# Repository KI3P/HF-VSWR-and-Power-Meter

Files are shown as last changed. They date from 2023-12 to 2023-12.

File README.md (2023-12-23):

# HF-VSWR-and-Power-Meter

System that measures the VSWR and power level of transmitter signals in the HF bands (3.5 MHz to 30 MHz) with better than 5% accuracy for VSWRs below 3.0. For a detailed explanation of its operation, see [its project page](https://ko4thb.github.io/2023/12/23/vswr_and_power_meter.html).

Gerbers were generated for manufacture by JLCPCB.

Credit: thanks to [G3TXQ](http://karinya.net/g3txq/swr_meter/) for sharing his SWR meter design and [schematic diagram](http://karinya.net/g3txq/swr_meter/schematic.jpg). Thanks to N7DDC for sharing the design of the [ATU-100 antenna tuner](https://github.com/Dfinitski/N7DDC-ATU-100-mini-and-extended-boards). And to W2AEW for his [excellent explanation](https://www.youtube.com/watch?v=byF1FLdbUiA) of how a directional coupler works. IN3OTD has an [online calculator](https://www.qsl.net/in3otd/parallr.html) for synthesizing arbitrary resistor values from standard value.  All these were tremendously helpful as I designed this VSWR meter.

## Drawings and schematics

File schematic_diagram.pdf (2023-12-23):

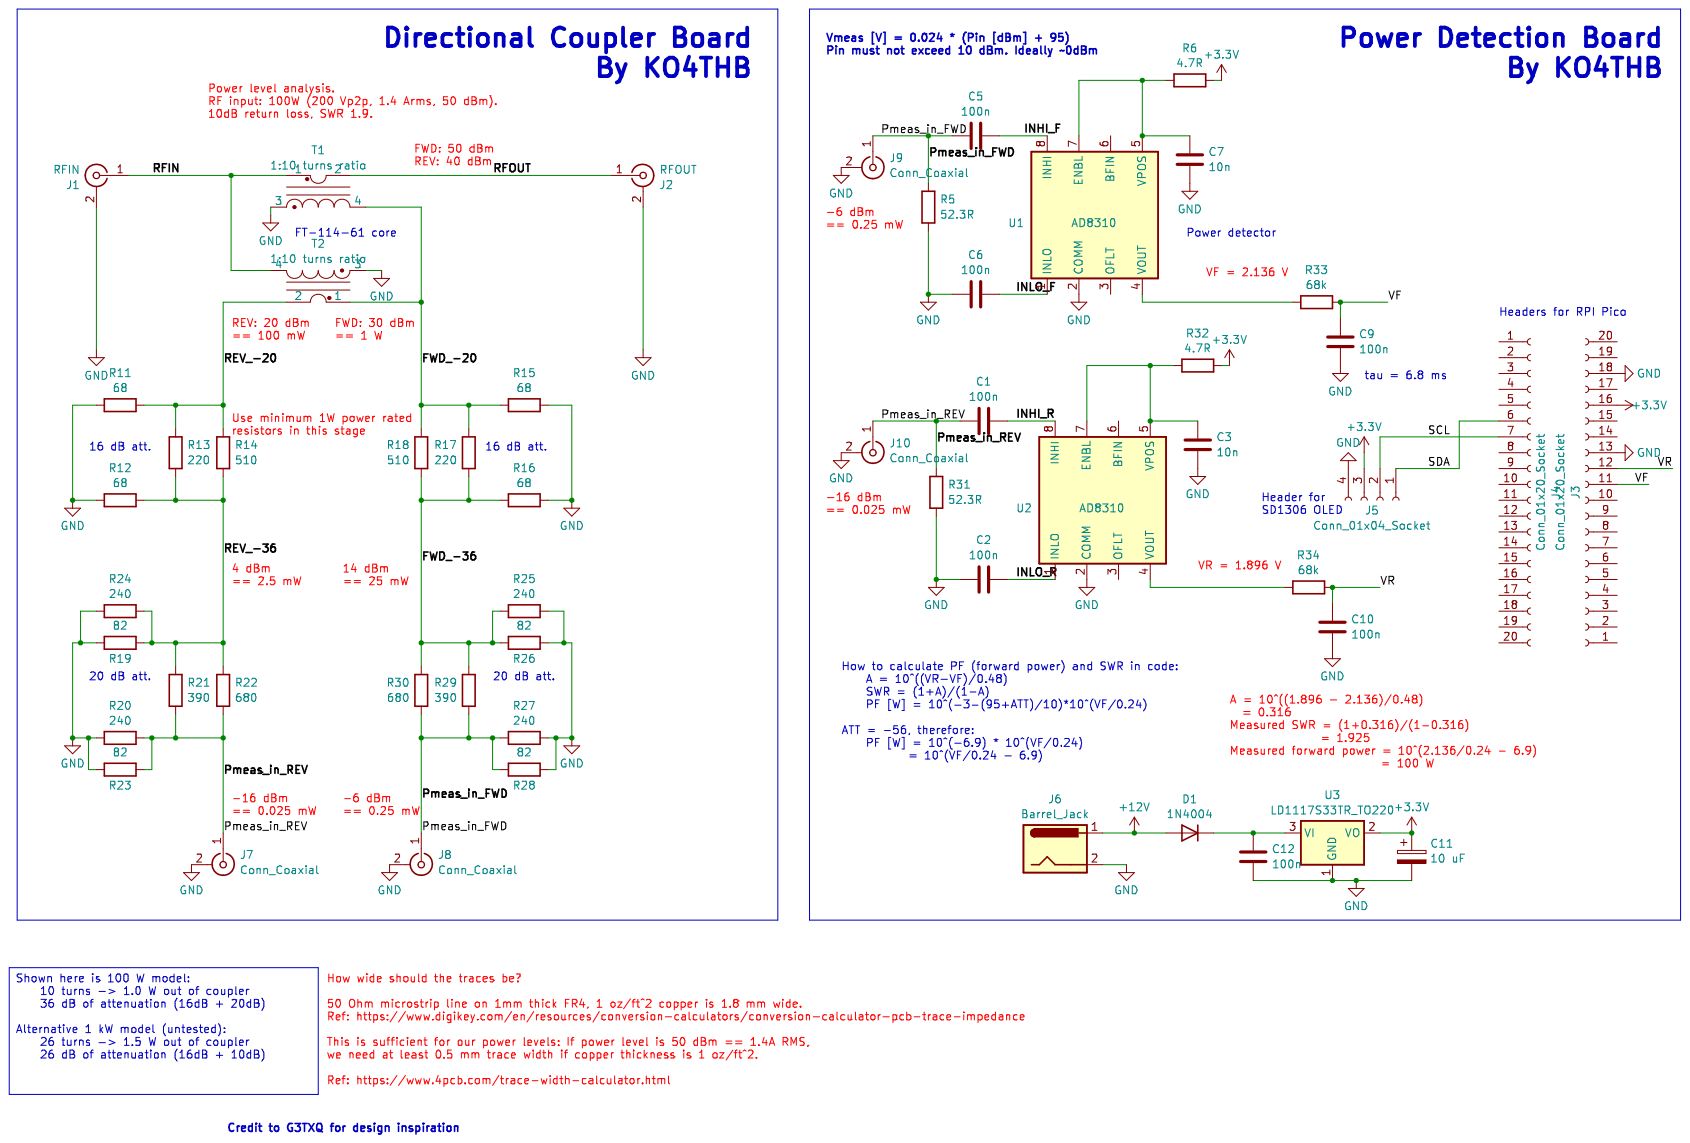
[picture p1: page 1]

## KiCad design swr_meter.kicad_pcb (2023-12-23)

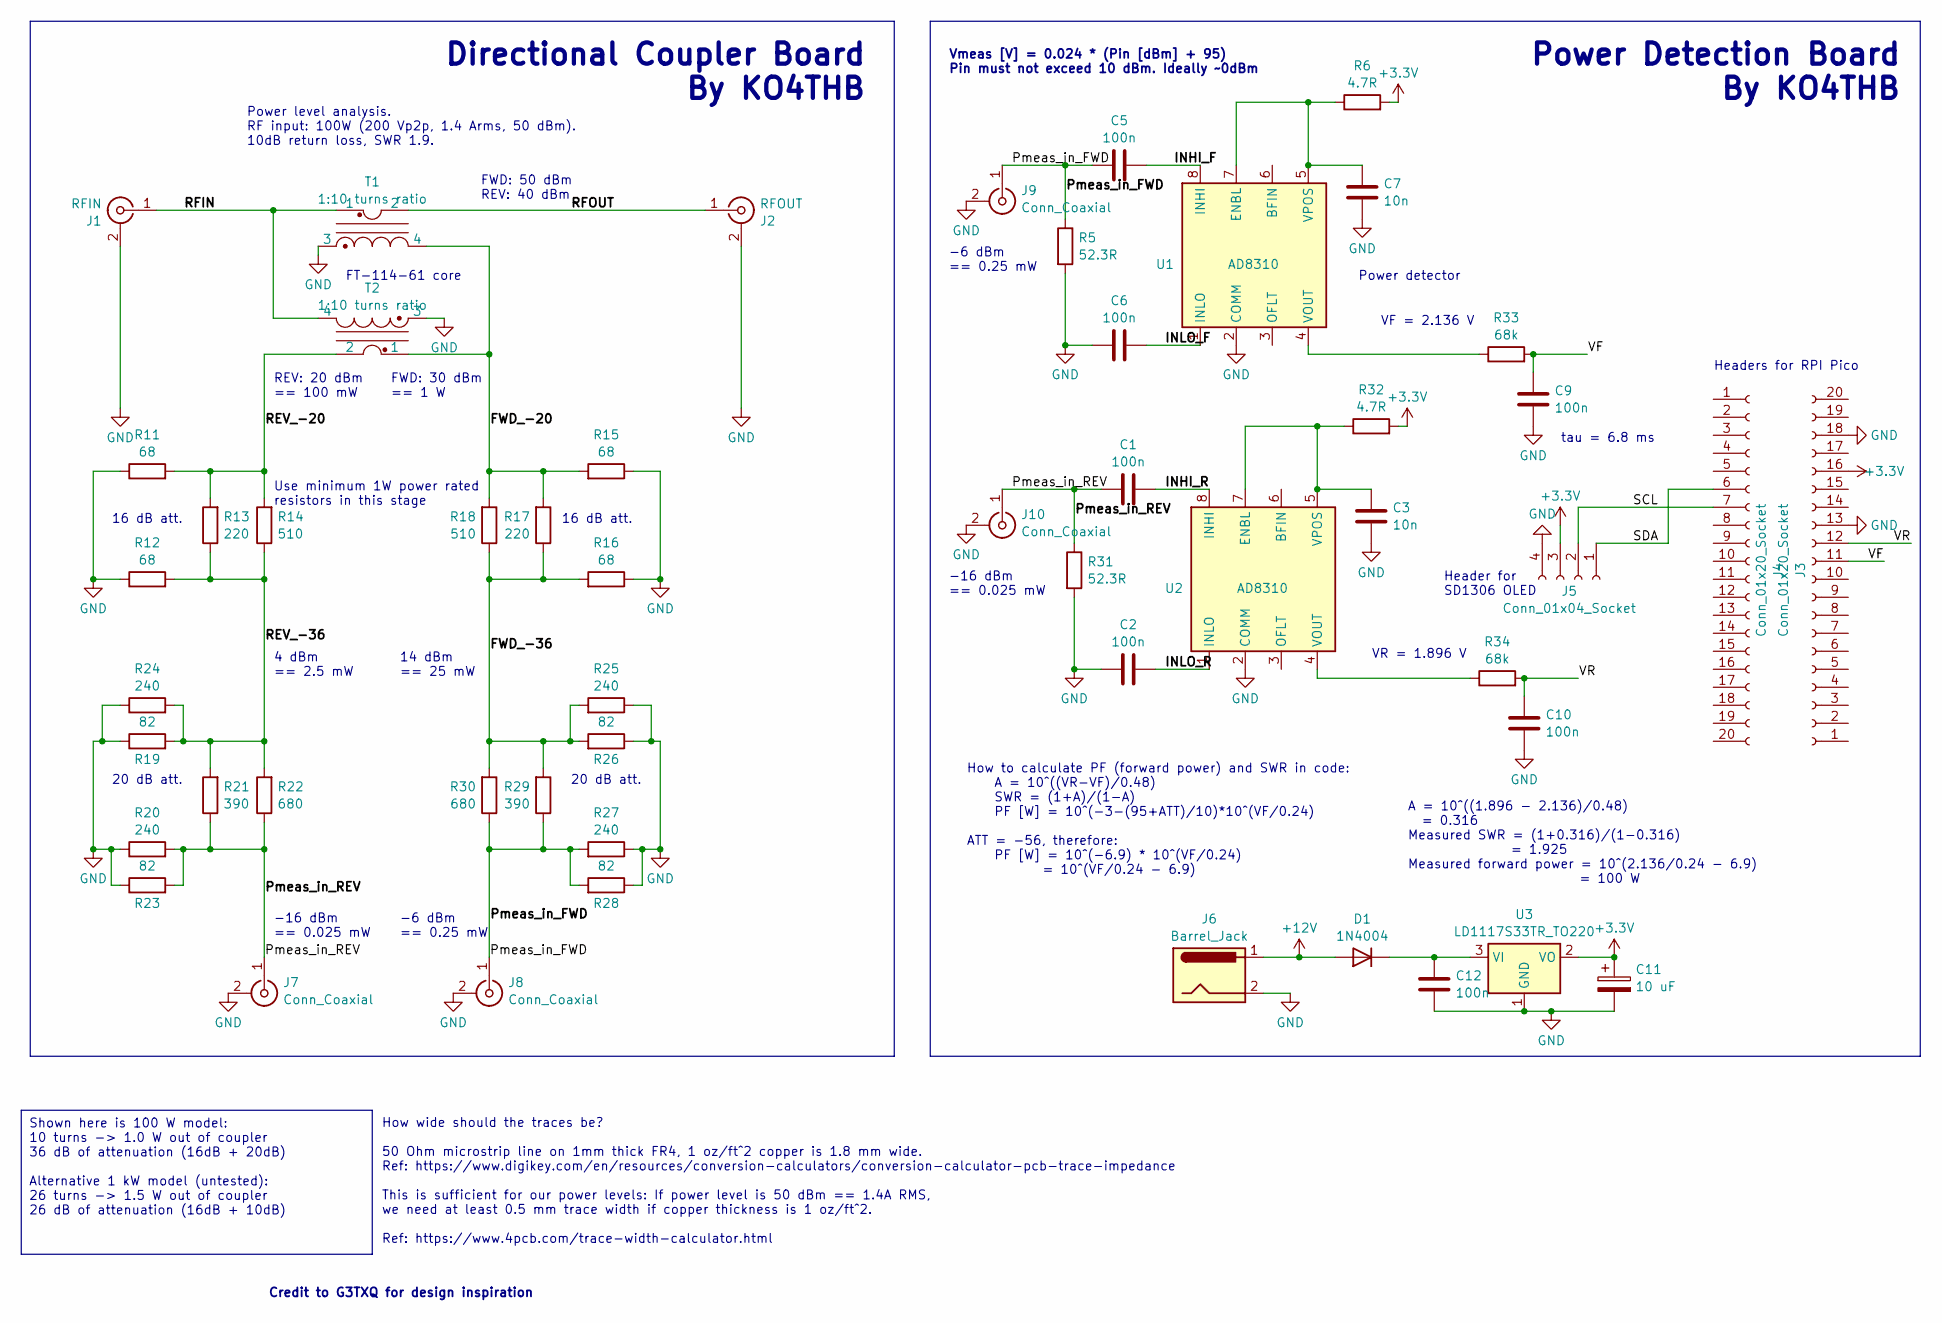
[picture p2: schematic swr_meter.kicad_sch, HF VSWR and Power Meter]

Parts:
C1, C2, C5, C6, C9, C10, C12: 100n; C_Disc_D9.0mm_W2.5mm_P5.00mm
C3, C7: 10n; C_Disc_D9.0mm_W2.5mm_P5.00mm
C11: 10 uF; CP_Radial_D6.3mm_P2.50mm
D1: 1N4004; D_DO-41_SOD81_P10.16mm_Horizontal
J1: RFIN; BNC_TEConnectivity_1478035_Horizontal
J2: RFOUT; BNC_TEConnectivity_1478035_Horizontal
J3, J4: Conn_01x20_Socket; PinHeader_1x20_P2.54mm_Vertical
J5: Conn_01x04_Socket; PinHeader_1x04_P2.54mm_Vertical
J6: Barrel_Jack; BarrelJack_Wuerth_6941xx301002
J7, J8, J9, J10: Conn_Coaxial; SMA_Amphenol_901-144_Vertical
R5, R31: 52.3R; R_Axial_DIN0207_L6.3mm_D2.5mm_P10.16mm_Horizontal
R6, R32: 4.7R; R_Axial_DIN0207_L6.3mm_D2.5mm_P10.16mm_Horizontal
R11, R12, R15, R16: 68; R_Axial_DIN0414_L11.9mm_D4.5mm_P15.24mm_Horizontal
R13, R17: 220; R_Axial_DIN0414_L11.9mm_D4.5mm_P15.24mm_Horizontal
R14, R18: 510; R_Axial_DIN0414_L11.9mm_D4.5mm_P15.24mm_Horizontal
R19, R23, R26, R28: 82; R_Axial_DIN0414_L11.9mm_D4.5mm_P15.24mm_Horizontal
R20, R24, R25, R27: 240; R_Axial_DIN0414_L11.9mm_D4.5mm_P15.24mm_Horizontal
R21, R29: 390; R_Axial_DIN0414_L11.9mm_D4.5mm_P15.24mm_Horizontal
R22, R30: 680; R_Axial_DIN0414_L11.9mm_D4.5mm_P15.24mm_Horizontal
R33, R34: 68k; R_Axial_DIN0207_L6.3mm_D2.5mm_P10.16mm_Horizontal
T1, T2: 1:10 turns ratio; Transformer_Toroid_Horizontal_D14.0mm_Amidon-T50
U1, U2: AD8310; MSOP-8_3x3mm_P0.65mm
U3: LD1117S33TR_TO220; TO-220-3_Vertical

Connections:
+3.3V: C11.1, J3.16, J5.3, R6.2, R32.2, U3.2 (VO)
+12V: D1.2 (A), J6.1
/FWD_-20: R15.2, R17.2, R18.2, T1.4, T2.1
/FWD_-36: R16.2, R17.1, R18.1, R25.2, R26.2, R29.2, R30.2
/INHI_F: C5.2, U1.8 (INHI)
/INHI_R: C1.2, U2.8 (INHI)
/INLO_F: C6.2, U1.1 (INLO)
/INLO_R: C2.2, U2.1 (INLO)
/Pmeas_in_FWD: C5.1, J8.1 (In), J9.1 (In), R5.1, R27.2, R28.2, R29.1, R30.1
/Pmeas_in_REV: C1.1, J7.1 (In), J10.1 (In), R20.2, R21.1, R22.1, R23.2, R31.1
/REV_-20: R11.2, R13.2, R14.2, T2.2
/REV_-36: R12.2, R13.1, R14.1, R19.2, R21.2, R22.2, R24.2
/RFIN: J1.1 (In), T1.1, T2.4
/RFOUT: J2.1 (In), T1.2
/SCL: J4.7, J5.2
/SDA: J4.6, J5.1
/VF: C9.2, J3.11, R33.2
/VR: C10.2, J3.12, R34.2
GND: C2.1, C3.1, C6.1, C7.1, C9.1, C10.1, C11.2, C12.1, J1.2 (Ext), J2.2 (Ext), J3.13, J3.18, J5.4, J6.2, J7.2 (Ext), J8.2 (Ext), J9.2 (Ext), J10.2 (Ext), R5.2, R11.1, R12.1, R15.1, R16.1, R19.1, R20.1, R23.1, R24.1, R25.1, R26.1, R27.1, R28.1, R31.2, T1.3, T2.3, U1.2 (COMM), U2.2 (COMM), U3.1 (GND)
unnamed: C12.2, D1.1 (K), U3.3 (VI)
unnamed: C7.2, R6.1, U1.5 (VPOS), U1.7 (ENBL)
unnamed: R33.1, U1.4 (VOUT)
unnamed: C3.2, R32.1, U2.5 (VPOS), U2.7 (ENBL)
unnamed: R34.1, U2.4 (VOUT)

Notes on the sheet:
Shown here is 100 W model: 10 turns -> 1.0 W out of coupler 36 dB of attenuation (16dB + 20dB) Alternative 1 kW model (untested): 26 turns -> 1.5 W out of coupler 26 dB of attenuation (16dB + 10dB)
-16 dBm == 0.025 mW
4 dBm == 2.5 mW
Power level analysis. RF input: 100W (200 Vp2p, 1.4 Arms, 50 dBm). 10dB return loss, SWR 1.9.
Power Detection Board By KO4THB
VR = 1.896 V
Use minimum 1W power rated resistors in this stage
FWD: 30 dBm == 1 W
20 dB att.
FWD: 50 dBm REV: 40 dBm
Headers for RPI Pico
tau = 6.8 ms
FT-114-61 core
Header for SD1306 OLED
14 dBm == 25 mW
-6 dBm == 0.25 mW
REV: 20 dBm == 100 mW
16 dB att.
How to calculate PF (forward power) and SWR in code: A = 10^((VR-VF)/0.48) SWR = (1+A)/(1-A) PF [W] = 10^(-3-(95+ATT)/10)*10^(VF/0.24) ATT = -56, therefore: PF [W] = 10^(-6.9) * 10^(VF/0.24) = 10^(VF/0.24 - 6.9)
Vmeas [V] = 0.024 * (Pin [dBm] + 95) Pin must not exceed 10 dBm. Ideally ~0dBm
VF = 2.136 V
Power detector
How wide should the traces be? 50 Ohm microstrip line on 1mm thick FR4, 1 oz/ft^2 copper is 1.8 mm wide. Ref: https://www.digikey.com/en/resources/conversion-calculators/conversion-calculator-pcb-trace-impedance This is sufficient for our power levels: If power level is 50 dBm == 1.4A RMS, we need 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
A = 10^((1.896 - 2.136)/0.48) = 0.316 Measured SWR = (1+0.316)/(1-0.316) = 1.925 Measured forward power = 10^(2.136/0.24 - 6.9) = 100 W
Directional Coupler Board By KO4THB
Credit to G3TXQ for design inspiration

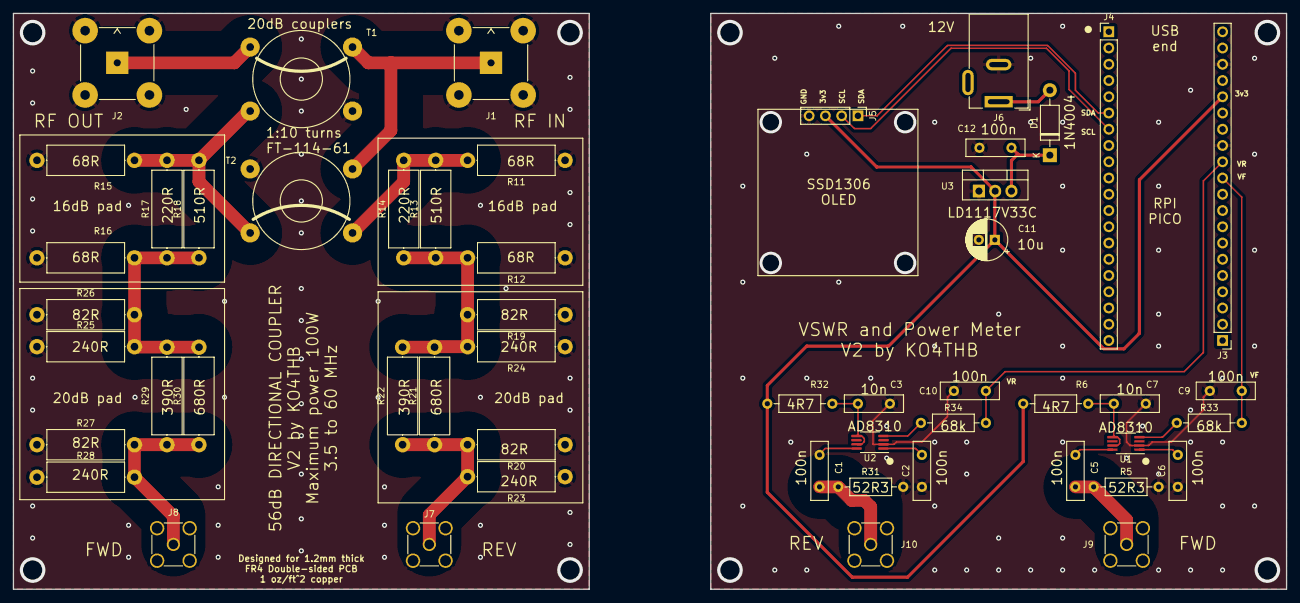
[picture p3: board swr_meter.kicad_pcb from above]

Board: 2 copper layers, 199.0 x 90.0 mm, 52 parts (0 on the bottom side), 24 nets.

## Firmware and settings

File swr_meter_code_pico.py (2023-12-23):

import machine
import utime
from machine import ADC
from ssd1306 import SSD1306_I2C

#madori button
#button1 = machine.Pin(15, machine.Pin.IN, machine.Pin.PULL_DOWN)
#Pinacolada Button
#button2 = machine.Pin(16, machine.Pin.IN, machine.Pin.PULL_DOWN)
#led = machine.Pin(25, machine.Pin.OUT)

# Display configuration
sda=machine.Pin(4)
scl=machine.Pin(5)
i2c=machine.I2C(0,sda=sda, scl=scl, freq=400000)
oled = SSD1306_I2C(128, 32, i2c)

# ADC configuration
# GPIO 26 == ADCf == board pin 31
# GPIO 27 == ADCr == board pin 32
ADCf = ADC(26)
ADCr = ADC(27)
# Attenuation between TX line and detector in dB
ATT_dB = -56
# only calculate SWR if forward power is greater than this
power_threshold_W = 0.5 

oled.text("KO4THB", 30, 0)
oled.text("SWR Meter", 10, 10)
oled.text("100 W max",10,20)
oled.show()

utime.sleep(5)

def read_and_average(ADCf,ADCr,N=100):
    # 100 iterations of this function takes 3.5 ms
    smf = 0
    smr = 0
    pkf = 0
    for k in range(N):
        f = ADCf.read_u16()
        smr += (ADCr.read_u16())**2
        smf += f**2
        if f > pkf:
            pkf = f
    return (smf/N)**(0.5) * 3.3 / 65536, (smr/N)**(0.5) * 3.3 / 65536, pkf* 3.3 / 65536

def measure_swr():
    Vf_RMS,Vr_RMS,Vf_peak = read_and_average(ADCf,ADCr,10000)

    Pf_RMS_W = 10**( Vf_RMS/0.24 -3 -(95+ATT_dB)/10)
    Pf_peak_W = 10**( Vf_peak/0.24 -3 -(95+ATT_dB)/10)
    
    A = 10**((Vr_RMS - Vf_RMS)/0.48)
    if Pf_peak_W > power_threshold_W:
        SWR = (1+A)/(1-A)
        SWR_inac = 0.0
    else:
        SWR = 0.0
        SWR_inac = (1+A)/(1-A)
        
    return Pf_RMS_W, Pf_peak_W , SWR, SWR_inac, Vf_RMS, Vr_RMS

while True:
    Pf_RMS,Pf_peak,swr,swr_inac, Vf, Vr = measure_swr()
    machine.Pin(25, machine.Pin.OUT).value(1)
    utime.sleep(0.05)
    machine.Pin(25, machine.Pin.OUT).value(0)
    
    oled.fill(0)
    oled.text("PR=%2.1f"%Pf_RMS, 0, 0)
    oled.text("PP=%2.1f"%Pf_peak, 64, 0)
    oled.text("SWR=%3.2f"%swr, 0, 10)
    oled.text(" S*=%3.2f"%swr_inac, 64, 10)
    oled.text("Vf=%4.3f"%Vf, 0, 20)
    oled.text("Vr=%4.3f"%Vr, 64, 20)
    oled.show()
    #utime.sleep(0.5)
